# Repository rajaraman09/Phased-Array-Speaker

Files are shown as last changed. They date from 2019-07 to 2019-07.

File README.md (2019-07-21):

# Phased-Array-Speaker

Introduction
For our ECE final project, we designed and built an array of 12 independently-controllable speakers to implement an acoustic phased-array system. 
The system samples a standard audio input signal at approximately 44.1 kHz, and then outputs this signal to each of 12 speakers, each with a variable delay. 
The idea behind a phased-array is that by changing how the speakers are driven the angle of the maximum intensity of the output wave can be shifted. This will be further explored in the high level design of the project.
This type of array was built to be able to support various other more advanced design challenges, including longer-range acoustic modem transmission and sonar imaging.

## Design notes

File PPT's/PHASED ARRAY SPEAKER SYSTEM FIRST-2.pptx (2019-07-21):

## PHASED ARRAY SPEAKER SYSTEM

Under the guidance of,
S. Bibin Sam Paul
Assistant Professor (sr. Gr.)

By,
MohammedArsath(120051601063)
RajaRaman.G(120051601094)
Rohit Kumar.S(120051601101)
Final Year, ECE - B

## PHASED ARRAY SPEAKERS

- Over the past few decades, digital signal processors (DSPs) have become available at a reasonable cost. This forces the question Now that it is possible to individually control the magnitude and phase of every loudspeaker in an array called phase array speaker system.
- Manipulating the magnitude and phase of every loudspeaker in an array of loudspeakers is commonly referred to as “beam steering.”

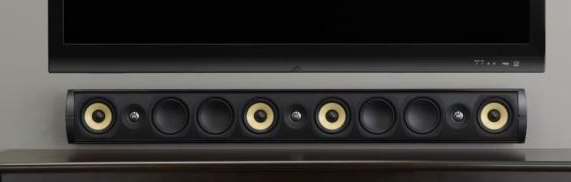
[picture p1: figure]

Line Array systems

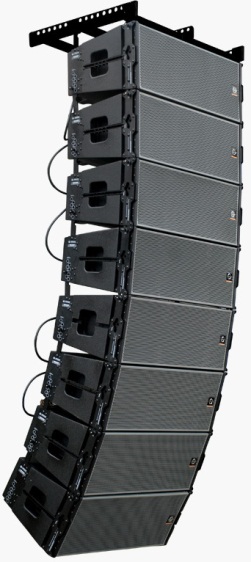
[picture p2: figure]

Phase Array systems

## OBJECTIVE

- The aim of the phased array speakers is to provide the maximum sound coverage over an entire area along with best sound clarity. The voices and the sound effects could be more easily differentiated. This system is comparatively cheaper when compared with its counterparts.

## INTRODUCTION

- A phased array speaker system to generate flexible, directional sound.
- The system samples a standard audio input signal at approximately 44.1 kHz, and then outputs this signal to each of 6-12 speakers, each with a variable delay.
- This simple technique allows audio frequency sound to be heard in only selected regions within the room or other auditory space.
- Multiple regions with multiple soundtracks can be created by simultaneously playing variously delayed soundtracks over each of the speakers in the array.
            - Sound waves from different loudspeakers can both combine or cancel depending on the relative phase relationships between the sound waves, it is possible to manipulate the phase (and magnitude) of the sound from two or more loudspeakers to control where the sound cancels and where the sound sums.

## HARDWARE DESIGN

X12

STANDARD AUDIO INPUT

INPUT BUFFER/LEVEL SHIFTER

AADC

ATMEGA 328 MICROCONTROLLER

DAC

SPEAKER AMPLIFIER

## SOFTWARE USED

- WinAVR used for programming the microcontroller.
- EAGLE software to design circuits for fabrication.

## PRE AMPLIFIER CIRCUIT

- Corner frequency of this input high pass filter 1/(RC)= 1/(.1u*80k)
=125Khz.
- The amplification factor is 1+(R1/R2)=1+(200k/150k)
=2.33

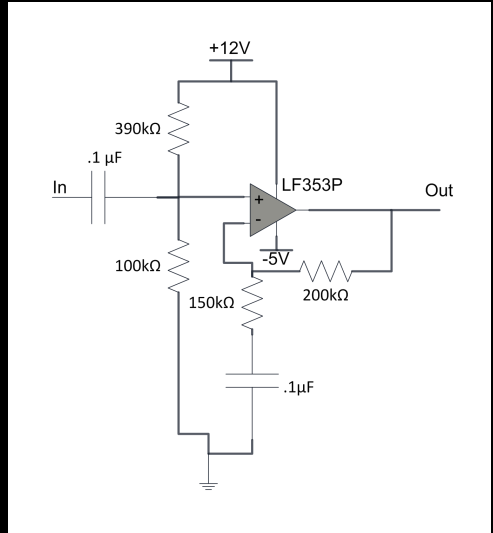
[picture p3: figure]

## DESCRIPTION

- The first stage is a high pass filter and re-biasing circuit, implemented by the first capacitor and the resistor divider.
- The second stage of the input amplifier is implemented with an LF353P Op--Amp in a non-inverting amplifier.
- It amplifies only the high frequency components due to the capacitor between the lower resistor and ground.
- Voltage swing from -1V to +1V to be converted to -2.33V to +2.33V finally it will be almost double to 5v.

## PRE AMPLIFIER ON EAGLE SOFTWARE

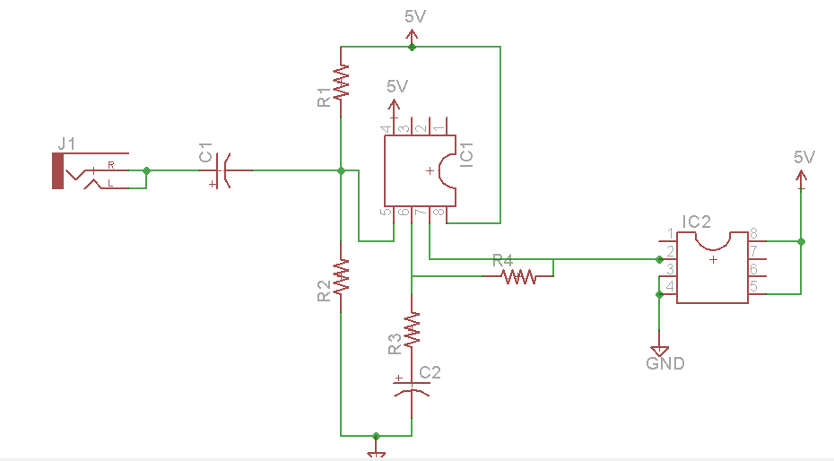
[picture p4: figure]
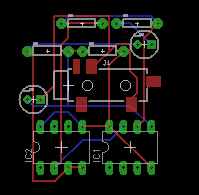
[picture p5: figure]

## POST AMPLIFIER CIRCUIT

- Low pass filter is used to reject all frequencies that are not in the audible region.
- The cut off frequency is about 23kHz.
- Two passive RC filters because cascading two RC filters has a gain of --6dB at the cut off frequency.

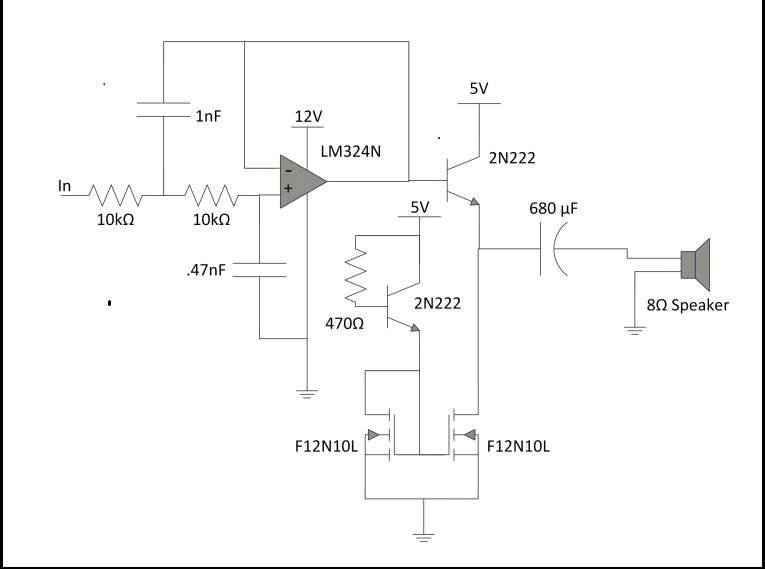
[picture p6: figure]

## POST AMPLIFIER ON EAGLE SOFTWARE

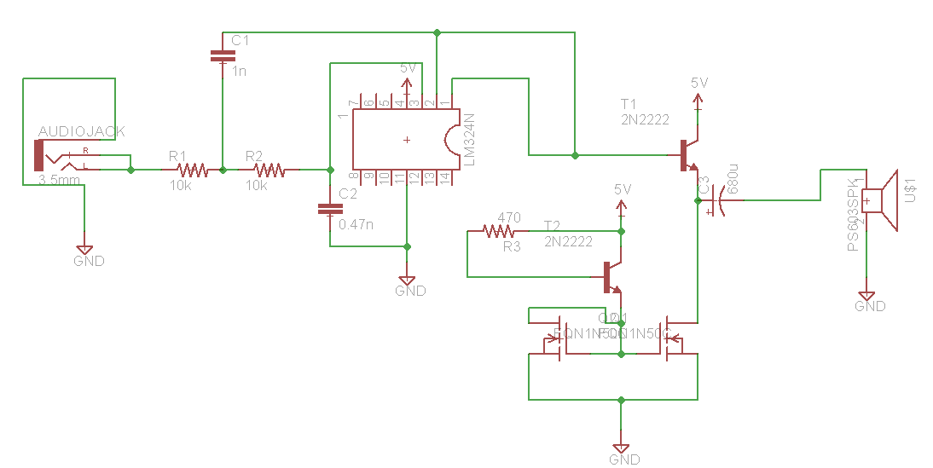
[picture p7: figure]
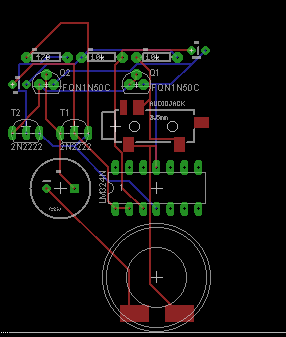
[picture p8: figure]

## Sound Beam Angle

Given Data
lamda=wavelength of sound wave
d=distance between adjacent speakers
td=time delay between signals going to adjacent speakers

θ=sina((−V_s /2 πd).td)
Vs=lamda*f

## OUTPUT FOR VIEWING ANGLE

For Time Delay=0

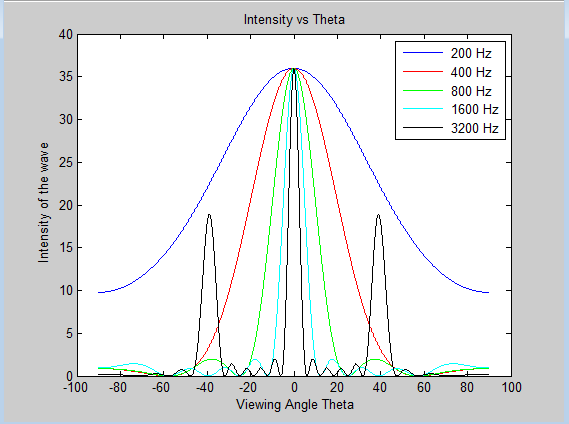
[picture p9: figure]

## SPEAKER ALIGNMENT

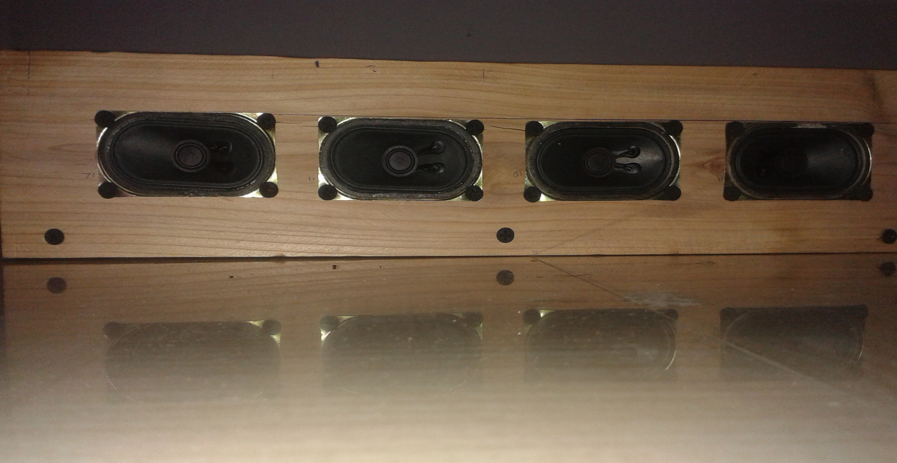
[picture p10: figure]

## APPLICATIONS

- Quadraphonic
- Sonar testing apparatus
- Enhancing bass

## WORKS To Do

- Circuit design for ADC
- Circuit Design for Atmega
- Generation of 12 different Phase to drive speakers
- Circuit Design of DAC
- Test the Module

## REFERENCES

- Paul Crilly, Richard Hartnett, Rosie Santrach, Carlos Palenzuela Department of Engineering, Electrical Engineering, U.S. Coast Guard Academy, New London “A Novel Approach to Teaching Phased Array Antenna Systems ”

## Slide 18

THANK YOU

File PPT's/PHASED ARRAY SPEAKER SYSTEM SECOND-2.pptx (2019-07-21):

## PHASED ARRAY SPEAKER SYSTEM

Under the guidance of,
S. Bibin Sam Paul
Assistant Professor (sr. Gr.)

By,
MohammedArsath(120051601063)
RajaRaman.G(120051601094)
Rohit Kumar.S(120051601101)
Final Year, ECE - B

## PHASED ARRAY SPEAKERS

- Over the past few decades, digital signal processors (DSPs) have become available at a reasonable cost. This forces the question Now that it is possible to individually control the magnitude and phase of every loudspeaker in an array called phase array speaker system.
- Manipulating the magnitude and phase of every loudspeaker in an array of loudspeakers is commonly referred to as “beam steering.”


Line Array systems


Phase Array systems

## OBJECTIVE

- The aim of the phased array speakers is to provide the maximum sound coverage over an entire area along with best sound clarity. The voices and the sound effects could be more easily differentiated. This system is comparatively cheaper when compared with its counterparts.

## INTRODUCTION

- A phased array speaker system to generate flexible, directional sound.
- The system samples a standard audio input signal at approximately 44.1 kHz, and then outputs this signal to each of 6-12 speakers, each with a variable delay.
- This simple technique allows audio frequency sound to be heard in only selected regions within the room or other auditory space.
- Multiple regions with multiple soundtracks can be created by simultaneously playing variously delayed soundtracks over each of the speakers in the array.
            - Sound waves from different loudspeakers can both combine or cancel depending on the relative phase relationships between the sound waves, it is possible to manipulate the phase (and magnitude) of the sound from two or more loudspeakers to control where the sound cancels and where the sound sums.

## HARDWARE DESIGN

X12

STANDARD AUDIO INPUT

INPUT BUFFER/LEVEL SHIFTER

AADC

ATMEGA 644 MICROCONTROLLER

DAC

SPEAKER AMPLIFIER

## SOFTWARE USED

- WinAVR used for programming the microcontroller.
- EAGLE software to design circuits for fabrication.

## PRE AMPLIFIER CIRCUIT

- Corner frequency of this input high pass filter 1/(RC)= 1/(.1u*80k)
=125hz.
- The amplification factor is 1+(R1/R2)=1+(200k/150k)
=2.33


## DESCRIPTION

- The first stage is a high pass filter and re-biasing circuit, implemented by the first capacitor and the resistor divider.
- The second stage of the input amplifier is implemented with an LF353P Op--Amp in a non-inverting amplifier.
- It amplifies only the high frequency components due to the capacitor between the lower resistor and ground.
- Voltage swing from -1V to +1V to be converted to -2.33V to +2.33V finally it will be almost double to 5v.

## ALGORITHM

- Initialization of microcontroller.
- Declaration of buffers.
- Setting up of timer and ADC.
- Discrete audio signals are delayed with appropriate coding and o/p is sent to respective i/p pins of DAC.

## PRE AMPLIFIER ON EAGLE SOFTWARE

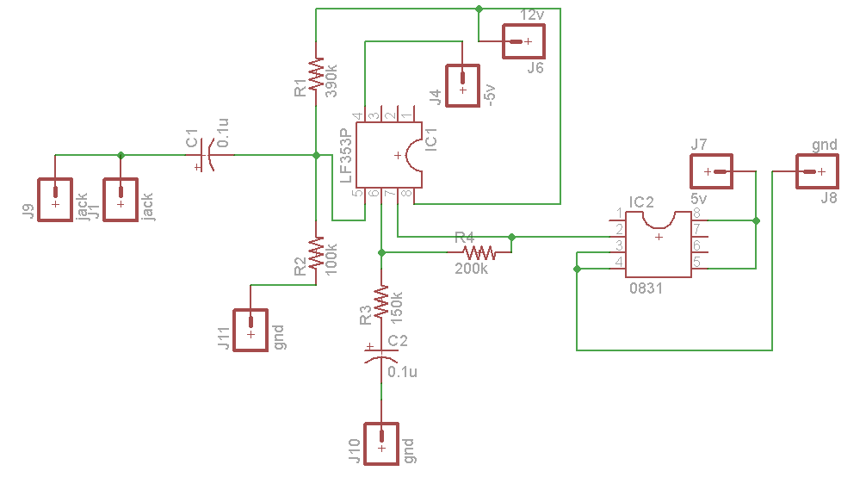
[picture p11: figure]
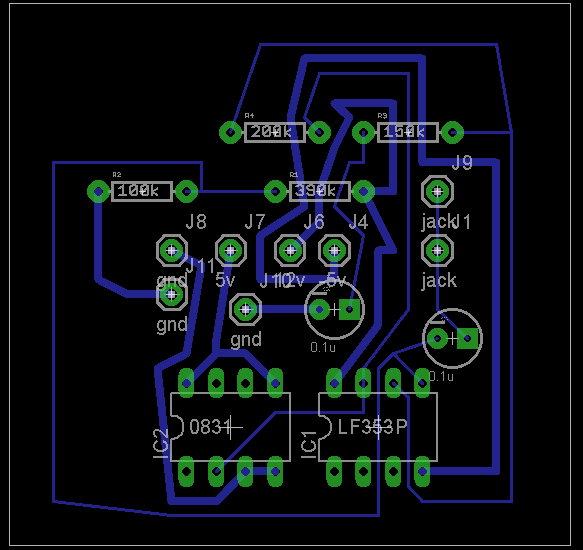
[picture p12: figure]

## POST AMPLIFIER ON EAGLE SOFTWARE

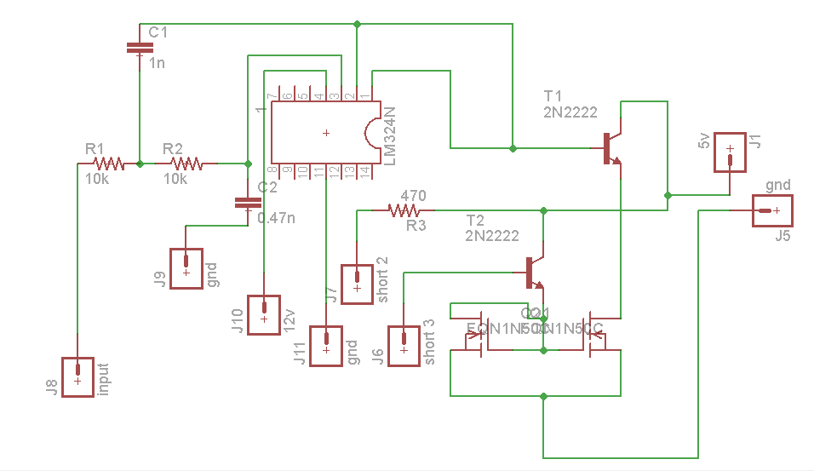
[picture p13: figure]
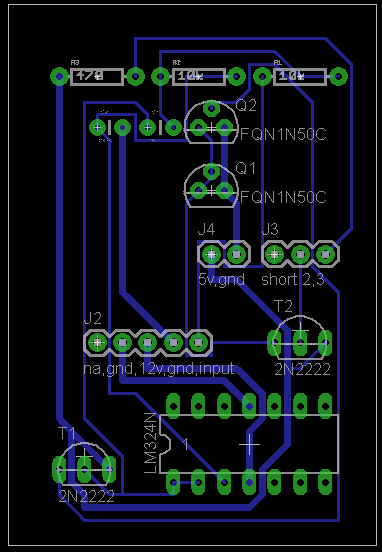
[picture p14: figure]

## DAC ON EAGLE SOFTWARE

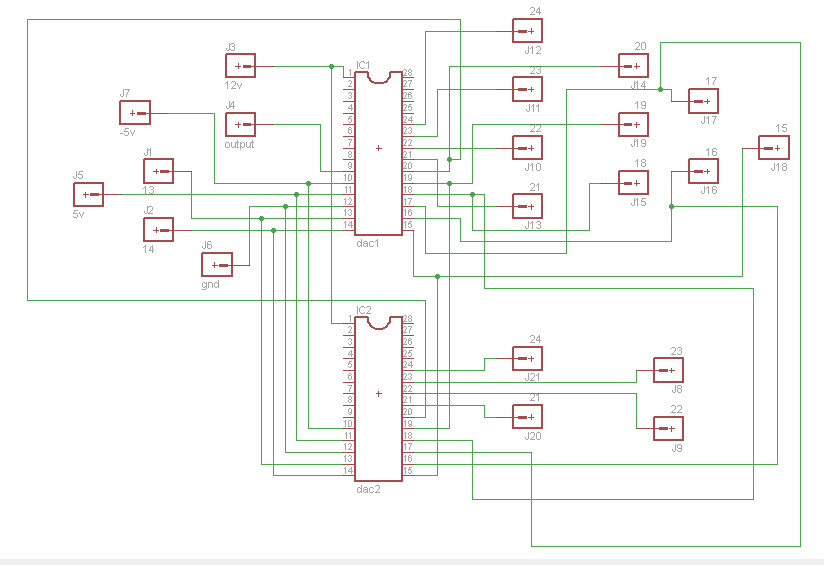
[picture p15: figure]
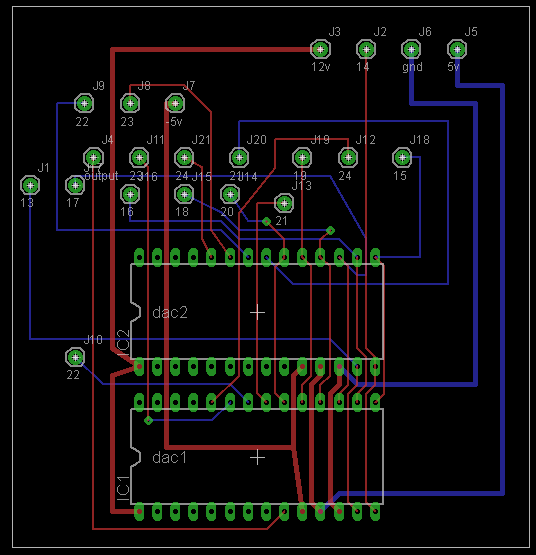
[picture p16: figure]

## PCB LAYER IN DAC DESIGN

TOP LAYER BOTTOM LAYER DOUBLE LAYER

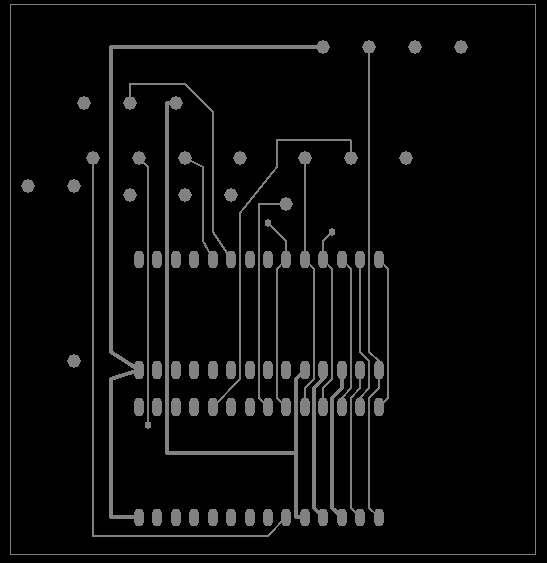
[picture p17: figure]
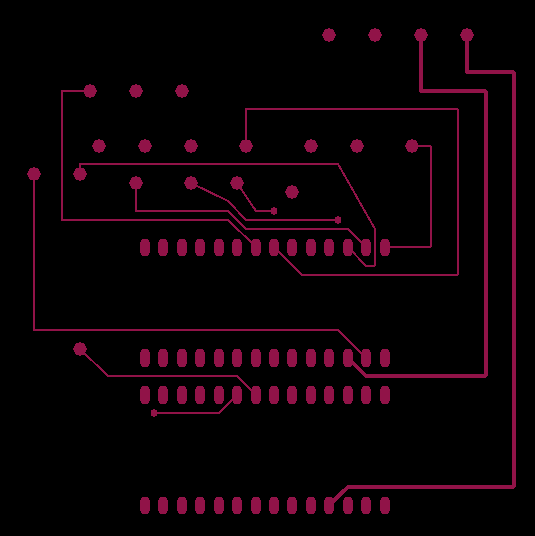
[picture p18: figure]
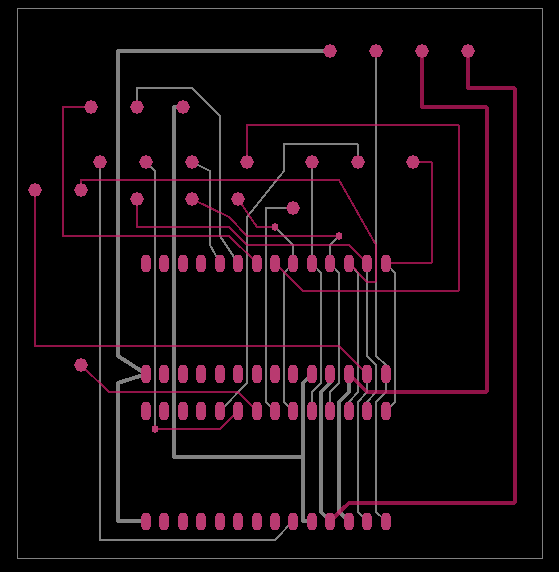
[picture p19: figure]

## PCB LAYER IN DAC DESIGN

DRILL LAYER SILK SCREEN OVERALL DESIGN

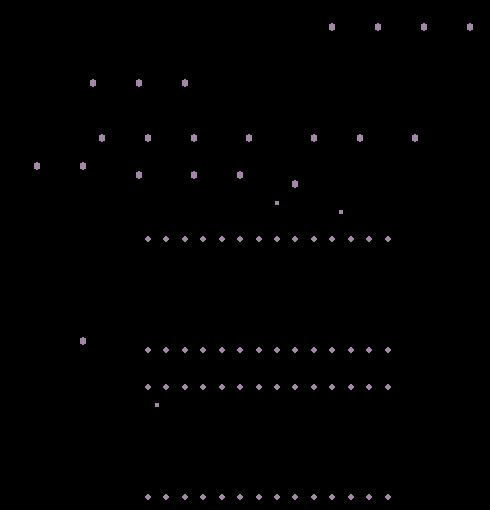
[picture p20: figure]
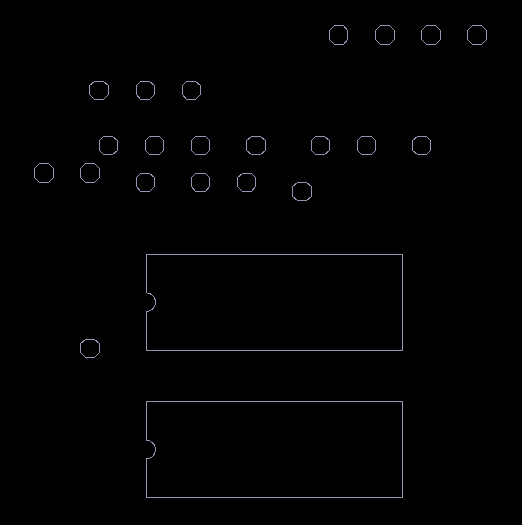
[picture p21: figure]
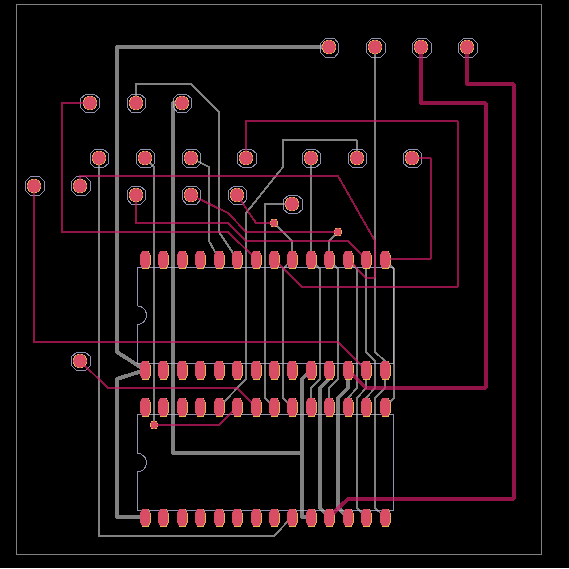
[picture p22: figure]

## PCB LAYER FOR POST AMPLIFIER

BOTTOM LAYER TOP LAYER SILK SCREEN

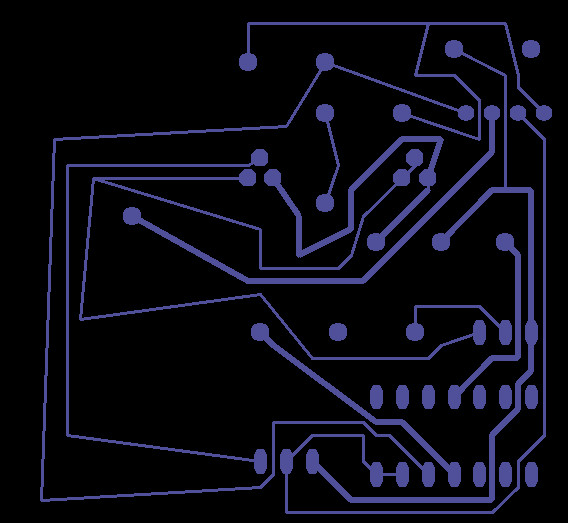
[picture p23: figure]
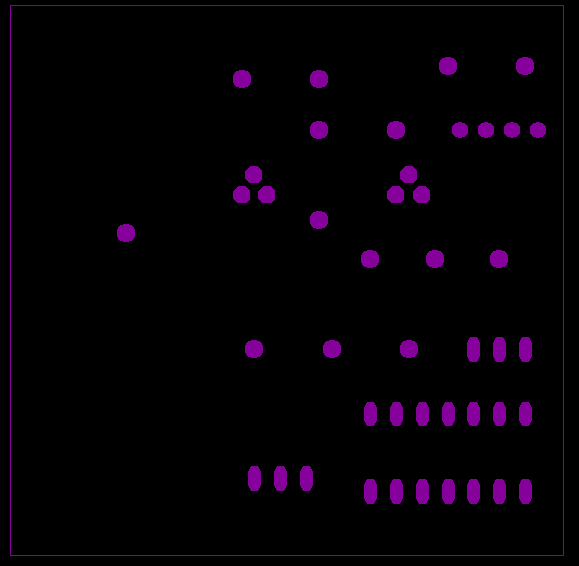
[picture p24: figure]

## PCB LAYER FOR POST AMPLIFIER

DRILL LAYER OVERALL DESIGN


## PCB LAYER FOR PRE AMPLIFIER

TOP LAYER BOTTOM LAYER SILK SCREEN LAYER

## PCB LAYER FOR PRE AMPLIFIER

DRILL LAYER OVERALL DESIGN

## SPEAKER ALIGNMENT


## APPLICATIONS

- Quadraphonic
- Sonar testing apparatus
- Enhancing bass

## WORKS To Do

- Soldering of components on PCB.
- Alignment of Component on hardware.

## REFERENCES

- Paul Crilly, Richard Hartnett, Rosie Santrach, Carlos Palenzuela Department of Engineering, Electrical Engineering, U.S. Coast Guard Academy, New London “A Novel Approach to Teaching Phased Array Antenna Systems ”

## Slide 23

THANK YOU

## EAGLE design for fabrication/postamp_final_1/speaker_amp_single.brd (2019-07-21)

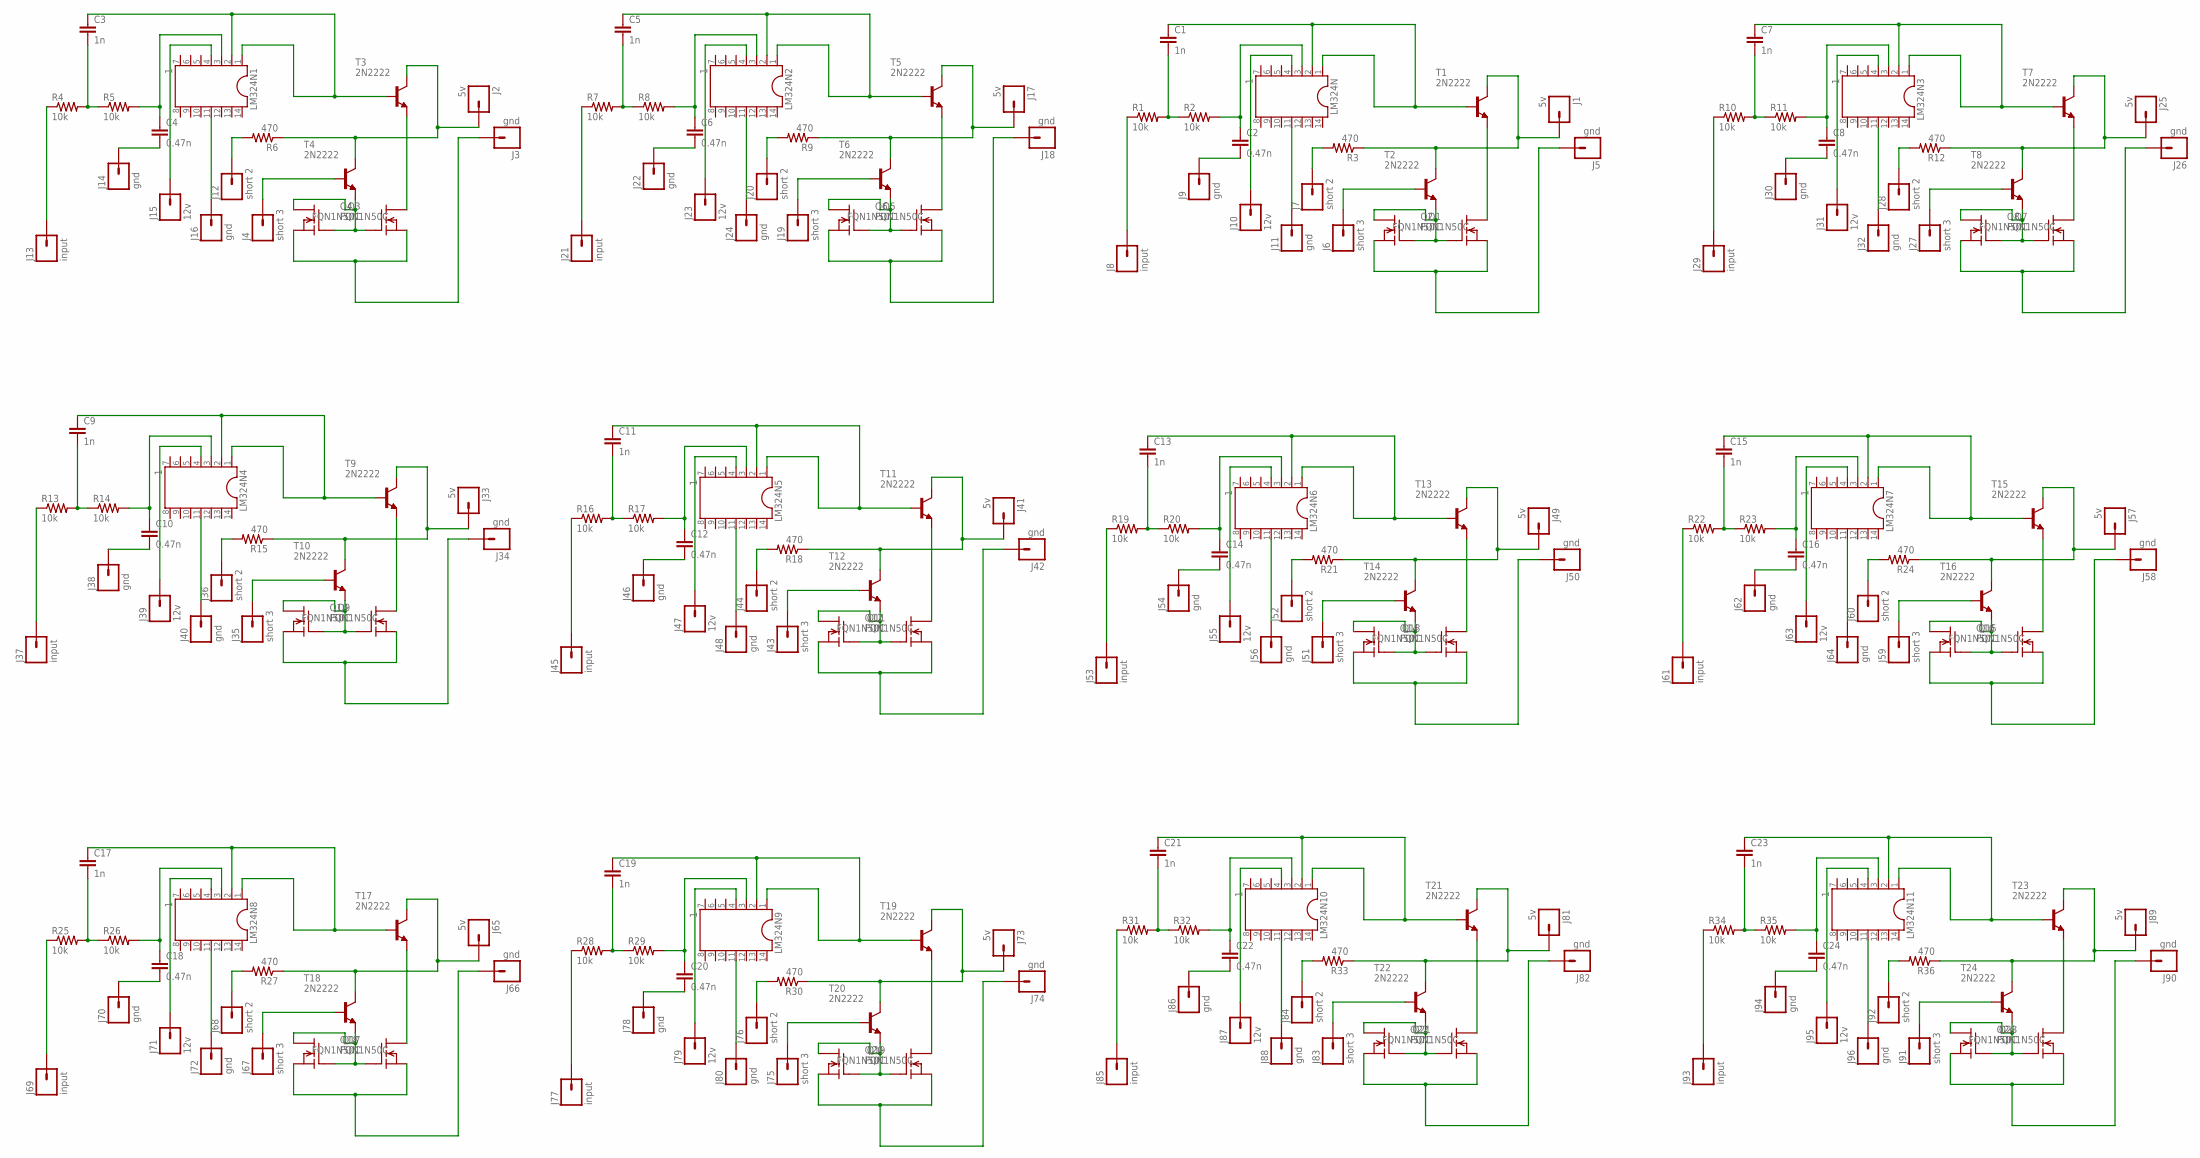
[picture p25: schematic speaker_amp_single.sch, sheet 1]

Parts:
C1, C3, C5, C7, C9, C11, C13, C15, C17, C19, C21, C23: 1n; CAP-PTH-SMALL
C2, C4, C6, C8, C10, C12, C14, C16, C18, C20, C22, C24: 0.47n; CAP-PTH-SMALL
J1, J2, J17, J25, J33, J41, J49, J57, J65, J73, J81, J89: 5v; 1X01
J3, J5, J9, J11, J14, J16, J18, J22, J24, J26, J30, J32, J34, J38, J40, J42, J46, J48, J50, J54, J56, J58, J62, J64, J66, J70, J72, J74, J78, J80, J82, J86, J88, J90, J94, J96: gnd; 1X01
J4, J6, J19, J27, J35, J43, J51, J59, J67, J75, J83, J91: short 3; 1X01
J7, J12, J20, J28, J36, J44, J52, J60, J68, J76, J84, J92: short 2; 1X01
J8, J13, J21, J29, J37, J45, J53, J61, J69, J77, J85, J93: input; 1X01
J10, J15, J23, J31, J39, J47, J55, J63, J71, J79, J87, J95: 12v; 1X01
LM324N, LM324N1, LM324N2, LM324N3, LM324N4, LM324N5, LM324N6, LM324N7, LM324N8, LM324N9, LM324N10, LM324N11: 1; DIL14
Q1, Q2, Q3, Q4, Q5, Q6, Q7, Q8, Q9, Q10, Q11, Q12, Q13, Q14, Q15, Q16, Q17, Q18, Q19, Q20, Q21, Q22, Q23, Q24: FQN1N50C; TO92
R1, R2, R4, R5, R7, R8, R10, R11, R13, R14, R16, R17, R19, R20, R22, R23, R25, R26, R28, R29, R31, R32, R34, R35: 10k; AXIAL-0.3
R3, R6, R9, R12, R15, R18, R21, R24, R27, R30, R33, R36: 470; AXIAL-0.3
T1, T2, T3, T4, T5, T6, T7, T8, T9, T10, T11, T12, T13, T14, T15, T16, T17, T18, T19, T20, T21, T22, T23, T24: 2N2222; TO92-EBC-OVAL

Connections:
unnamed: C1.2, R1.P$2 (2), R2.P$1 (1)
unnamed: C2.1, LM324N.3, R2.P$2 (2)
unnamed: C1.1, LM324N.1, LM324N.2, T1.B
unnamed: Q2.2 (D), T1.E
unnamed: Q1.1 (G), Q1.2 (D), Q2.1 (G), T2.E
unnamed: J7.1, R3.P$2 (2)
unnamed: J11.1, LM324N.11
unnamed: J6.1, T2.B
unnamed: J8.1, R1.P$1 (1)
unnamed: J1.1, R3.P$1 (1), T1.C, T2.C
unnamed: C2.2, J9.1
unnamed: J5.1, Q1.3 (S), Q2.3 (S)
unnamed: C3.2, R4.P$2 (2), R5.P$1 (1)
unnamed: J10.1, LM324N.4
unnamed: C4.1, LM324N1.3, R5.P$2 (2)
unnamed: C3.1, LM324N1.1, LM324N1.2, T3.B
unnamed: Q4.2 (D), T3.E
unnamed: Q3.1 (G), Q3.2 (D), Q4.1 (G), T4.E
unnamed: J2.1, R6.P$1 (1), T3.C, T4.C
unnamed: J3.1, Q3.3 (S), Q4.3 (S)
unnamed: J16.1, LM324N1.11
unnamed: J4.1, T4.B
unnamed: J13.1, R4.P$1 (1)
unnamed: C4.2, J14.1
unnamed: J15.1, LM324N1.4
unnamed: J12.1, R6.P$2 (2)
unnamed: C5.2, R7.P$2 (2), R8.P$1 (1)
unnamed: C6.1, LM324N2.3, R8.P$2 (2)
unnamed: C5.1, LM324N2.1, LM324N2.2, T5.B
unnamed: Q6.2 (D), T5.E
unnamed: Q5.1 (G), Q5.2 (D), Q6.1 (G), T6.E
unnamed: J17.1, R9.P$1 (1), T5.C, T6.C
unnamed: J18.1, Q5.3 (S), Q6.3 (S)
unnamed: J24.1, LM324N2.11
unnamed: J19.1, T6.B
unnamed: J21.1, R7.P$1 (1)
unnamed: C6.2, J22.1
unnamed: J23.1, LM324N2.4
unnamed: J20.1, R9.P$2 (2)
unnamed: C7.2, R10.P$2 (2), R11.P$1 (1)
unnamed: C8.1, LM324N3.3, R11.P$2 (2)
unnamed: C7.1, LM324N3.1, LM324N3.2, T7.B
unnamed: Q8.2 (D), T7.E
unnamed: Q7.1 (G), Q7.2 (D), Q8.1 (G), T8.E
unnamed: J25.1, R12.P$1 (1), T7.C, T8.C
unnamed: J26.1, Q7.3 (S), Q8.3 (S)
unnamed: J32.1, LM324N3.11
unnamed: J27.1, T8.B
unnamed: J29.1, R10.P$1 (1)
unnamed: C8.2, J30.1
unnamed: J31.1, LM324N3.4
unnamed: J28.1, R12.P$2 (2)
unnamed: C9.2, R13.P$2 (2), R14.P$1 (1)
unnamed: C10.1, LM324N4.3, R14.P$2 (2)
unnamed: C9.1, LM324N4.1, LM324N4.2, T9.B
unnamed: Q10.2 (D), T9.E
unnamed: Q9.1 (G), Q9.2 (D), Q10.1 (G), T10.E
unnamed: J33.1, R15.P$1 (1), T9.C, T10.C
unnamed: J34.1, Q9.3 (S), Q10.3 (S)
unnamed: J40.1, LM324N4.11
unnamed: J35.1, T10.B
unnamed: J37.1, R13.P$1 (1)
unnamed: C10.2, J38.1
unnamed: J39.1, LM324N4.4
unnamed: J36.1, R15.P$2 (2)
unnamed: C11.2, R16.P$2 (2), R17.P$1 (1)
unnamed: C12.1, LM324N5.3, R17.P$2 (2)
unnamed: C11.1, LM324N5.1, LM324N5.2, T11.B
unnamed: Q12.2 (D), T11.E
unnamed: Q11.1 (G), Q11.2 (D), Q12.1 (G), T12.E
unnamed: J41.1, R18.P$1 (1), T11.C, T12.C
unnamed: J42.1, Q11.3 (S), Q12.3 (S)
unnamed: J48.1, LM324N5.11
unnamed: J43.1, T12.B
unnamed: J45.1, R16.P$1 (1)
unnamed: C12.2, J46.1
unnamed: J47.1, LM324N5.4
unnamed: J44.1, R18.P$2 (2)
unnamed: C13.2, R19.P$2 (2), R20.P$1 (1)
unnamed: C14.1, LM324N6.3, R20.P$2 (2)
unnamed: C13.1, LM324N6.1, LM324N6.2, T13.B
unnamed: Q14.2 (D), T13.E
unnamed: Q13.1 (G), Q13.2 (D), Q14.1 (G), T14.E
unnamed: J49.1, R21.P$1 (1), T13.C, T14.C
unnamed: J50.1, Q13.3 (S), Q14.3 (S)
unnamed: J56.1, LM324N6.11
unnamed: J51.1, T14.B
unnamed: J53.1, R19.P$1 (1)
unnamed: C14.2, J54.1
unnamed: J55.1, LM324N6.4
unnamed: J52.1, R21.P$2 (2)
unnamed: C15.2, R22.P$2 (2), R23.P$1 (1)
unnamed: C16.1, LM324N7.3, R23.P$2 (2)
unnamed: C15.1, LM324N7.1, LM324N7.2, T15.B
unnamed: Q16.2 (D), T15.E
unnamed: Q15.1 (G), Q15.2 (D), Q16.1 (G), T16.E
unnamed: J57.1, R24.P$1 (1), T15.C, T16.C
unnamed: J58.1, Q15.3 (S), Q16.3 (S)
unnamed: J64.1, LM324N7.11
unnamed: J59.1, T16.B
unnamed: J61.1, R22.P$1 (1)
unnamed: C16.2, J62.1
unnamed: J63.1, LM324N7.4
unnamed: J60.1, R24.P$2 (2)
unnamed: C17.2, R25.P$2 (2), R26.P$1 (1)
unnamed: C18.1, LM324N8.3, R26.P$2 (2)
unnamed: C17.1, LM324N8.1, LM324N8.2, T17.B
unnamed: Q18.2 (D), T17.E
unnamed: Q17.1 (G), Q17.2 (D), Q18.1 (G), T18.E
unnamed: J65.1, R27.P$1 (1), T17.C, T18.C
unnamed: J66.1, Q17.3 (S), Q18.3 (S)
unnamed: J72.1, LM324N8.11
unnamed: J67.1, T18.B
unnamed: J69.1, R25.P$1 (1)
unnamed: C18.2, J70.1
unnamed: J71.1, LM324N8.4
unnamed: J68.1, R27.P$2 (2)
unnamed: C19.2, R28.P$2 (2), R29.P$1 (1)
unnamed: C20.1, LM324N9.3, R29.P$2 (2)
unnamed: C19.1, LM324N9.1, LM324N9.2, T19.B
unnamed: Q20.2 (D), T19.E
unnamed: Q19.1 (G), Q19.2 (D), Q20.1 (G), T20.E
unnamed: J73.1, R30.P$1 (1), T19.C, T20.C
unnamed: J74.1, Q19.3 (S), Q20.3 (S)
unnamed: J80.1, LM324N9.11
unnamed: J75.1, T20.B
unnamed: J77.1, R28.P$1 (1)
unnamed: C20.2, J78.1
unnamed: J79.1, LM324N9.4
unnamed: J76.1, R30.P$2 (2)
unnamed: C21.2, R31.P$2 (2), R32.P$1 (1)
unnamed: C22.1, LM324N10.3, R32.P$2 (2)
unnamed: C21.1, LM324N10.1, LM324N10.2, T21.B
unnamed: Q22.2 (D), T21.E
unnamed: Q21.1 (G), Q21.2 (D), Q22.1 (G), T22.E
unnamed: J81.1, R33.P$1 (1), T21.C, T22.C
unnamed: J82.1, Q21.3 (S), Q22.3 (S)
unnamed: J88.1, LM324N10.11
unnamed: J83.1, T22.B
unnamed: J85.1, R31.P$1 (1)
unnamed: C22.2, J86.1
unnamed: J87.1, LM324N10.4
unnamed: J84.1, R33.P$2 (2)
unnamed: C23.2, R34.P$2 (2), R35.P$1 (1)
unnamed: C24.1, LM324N11.3, R35.P$2 (2)
unnamed: C23.1, LM324N11.1, LM324N11.2, T23.B
unnamed: Q24.2 (D), T23.E
unnamed: Q23.1 (G), Q23.2 (D), Q24.1 (G), T24.E
unnamed: J89.1, R36.P$1 (1), T23.C, T24.C
unnamed: J90.1, Q23.3 (S), Q24.3 (S)
unnamed: J96.1, LM324N11.11
unnamed: J91.1, T24.B
unnamed: J93.1, R34.P$1 (1)
unnamed: C24.2, J94.1
unnamed: J95.1, LM324N11.4
unnamed: J92.1, R36.P$2 (2)

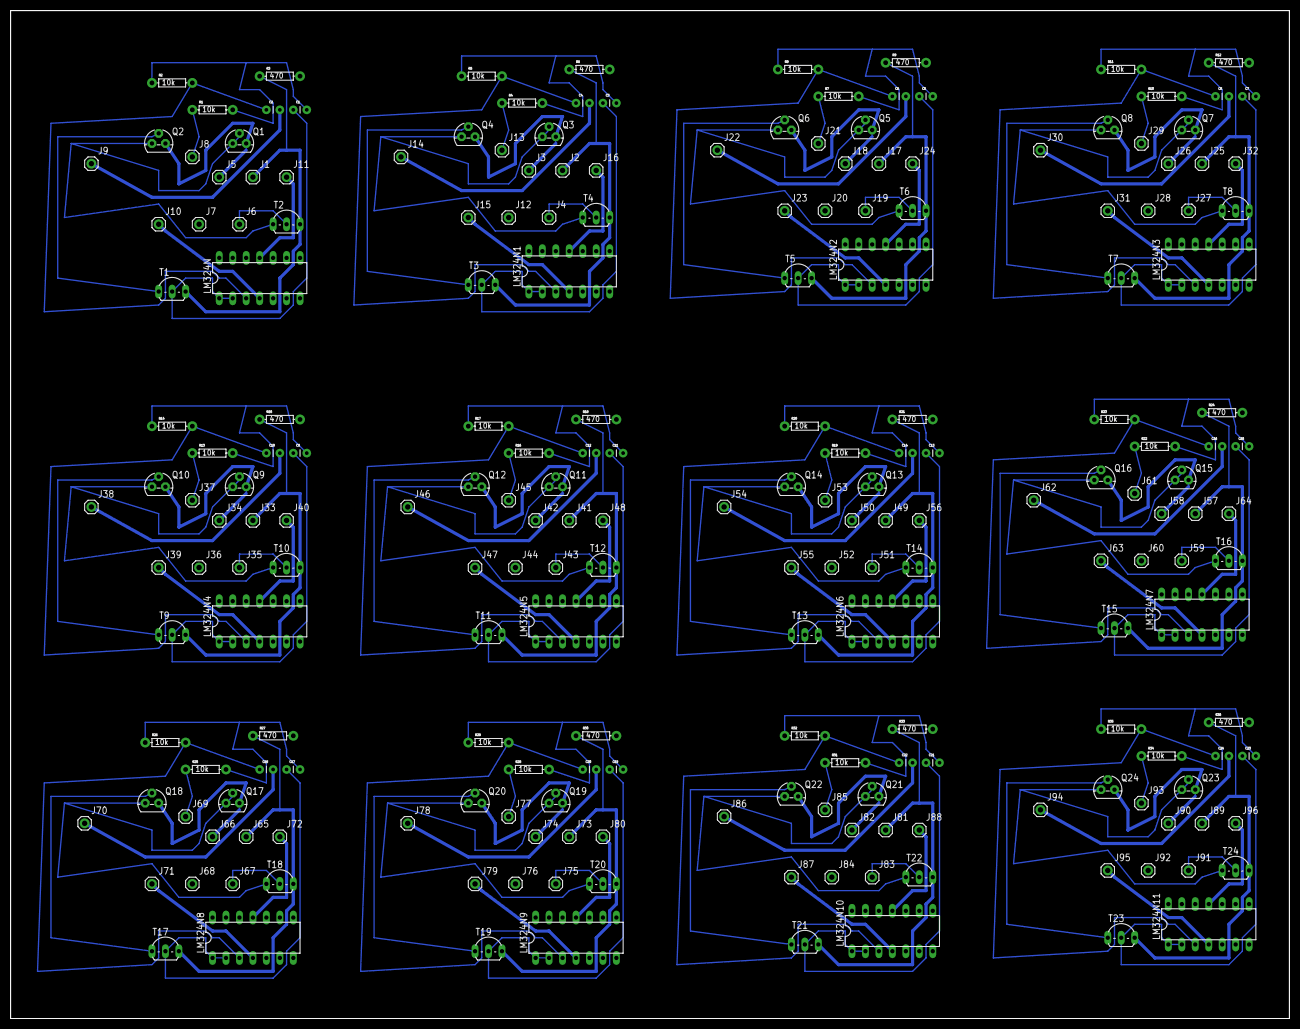
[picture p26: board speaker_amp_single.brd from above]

Board: 2 copper layers, 241.3 x 190.2 mm, 216 parts (0 on the bottom side), 156 nets.

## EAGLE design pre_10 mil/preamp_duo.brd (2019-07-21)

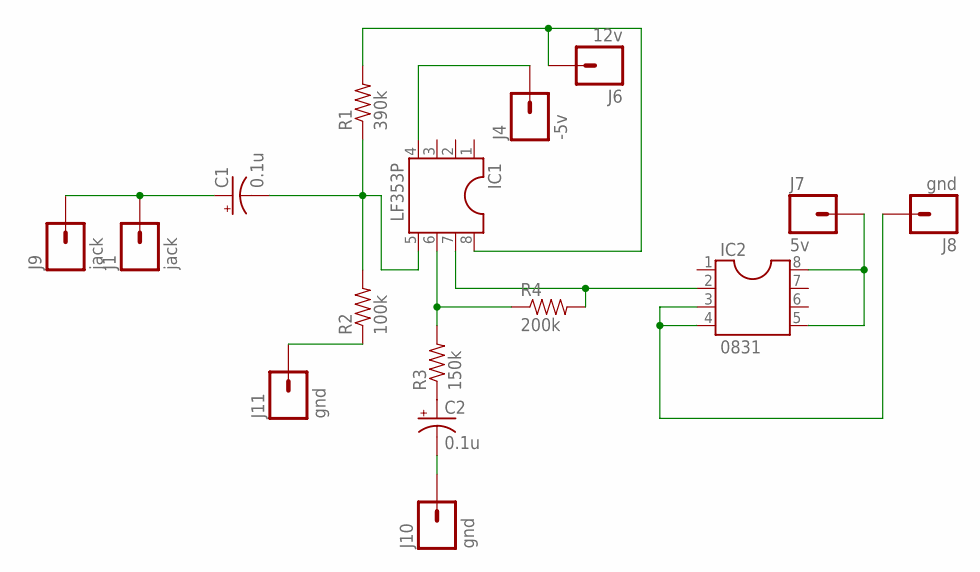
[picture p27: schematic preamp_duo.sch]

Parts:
C1, C2: 0.1u; CPOL-RADIAL-10UF-25V
IC1: LF353P; DIL08
IC2: 0831; DIL08
J1, J9: jack; 1X01
J4: -5v; 1X01
J6: 12v; 1X01
J7: 5v; 1X01
J8, J10, J11: gnd; 1X01
R1: 390k; AXIAL-0.3
R2: 100k; AXIAL-0.3
R3: 150k; AXIAL-0.3
R4: 200k; AXIAL-0.3

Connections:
unnamed: C1.2 (-), IC1.5, R1.P$1 (1), R2.P$2 (2)
unnamed: C1.1 (+), J1.1, J9.1
unnamed: IC1.8, J6.1, R1.P$2 (2)
unnamed: C2.1 (+), R3.P$1 (1)
unnamed: IC1.6, R3.P$2 (2), R4.P$1 (1)
unnamed: IC1.7, IC2.2, R4.P$2 (2)
unnamed: IC1.4, J4.1
unnamed: IC2.5, IC2.8, J7.1
unnamed: J11.1, R2.P$1 (1)
unnamed: IC2.3, IC2.4, J8.1
unnamed: C2.2 (-), J10.1

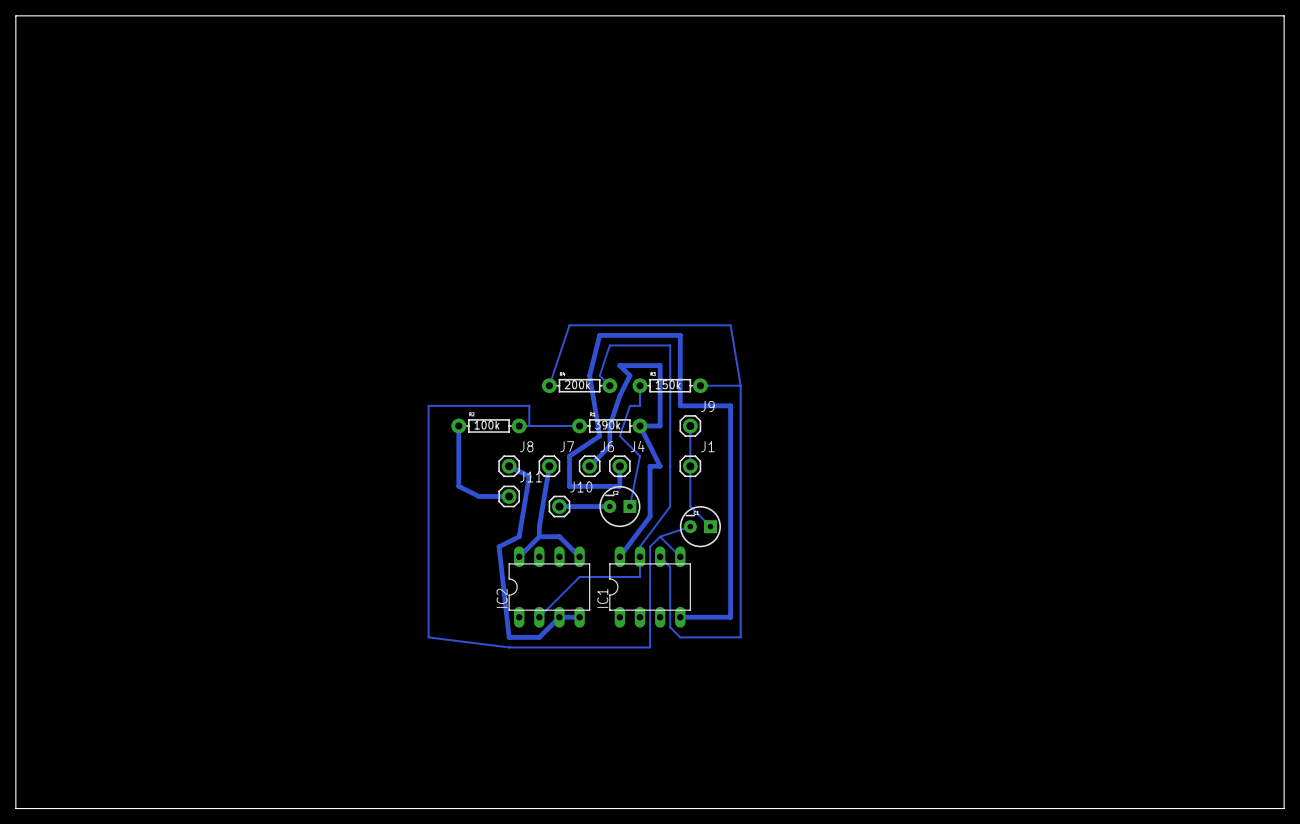
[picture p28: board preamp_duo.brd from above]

Board: 2 copper layers, 160.0 x 100.0 mm, 16 parts (0 on the bottom side), 11 nets.

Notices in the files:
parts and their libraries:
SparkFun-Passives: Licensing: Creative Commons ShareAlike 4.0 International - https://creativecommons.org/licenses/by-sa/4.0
